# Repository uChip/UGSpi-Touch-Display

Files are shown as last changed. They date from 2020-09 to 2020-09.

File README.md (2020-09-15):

# UGSpi-Touch-Display
 A case for Rpi Display intended for DIY CNC router controller

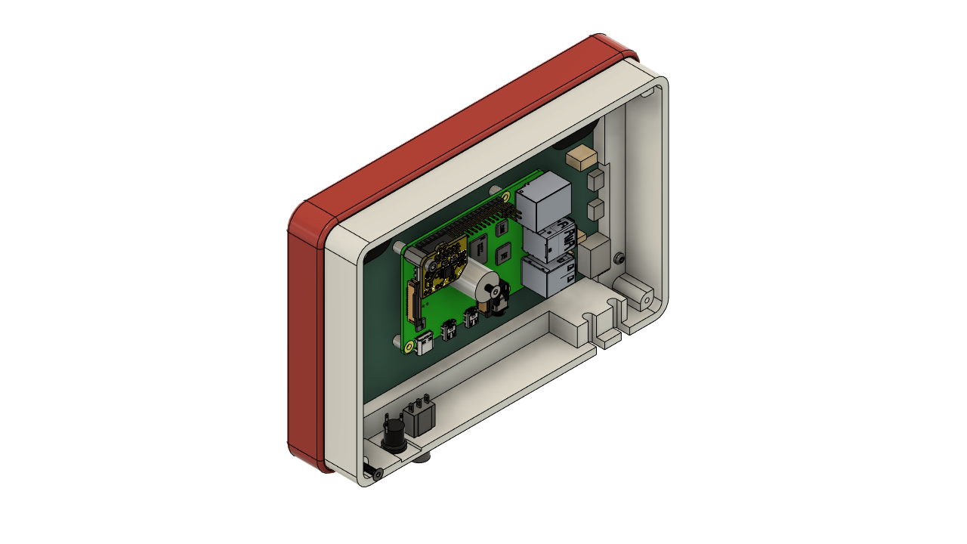
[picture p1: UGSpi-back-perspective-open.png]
UGSpi Case Rendering
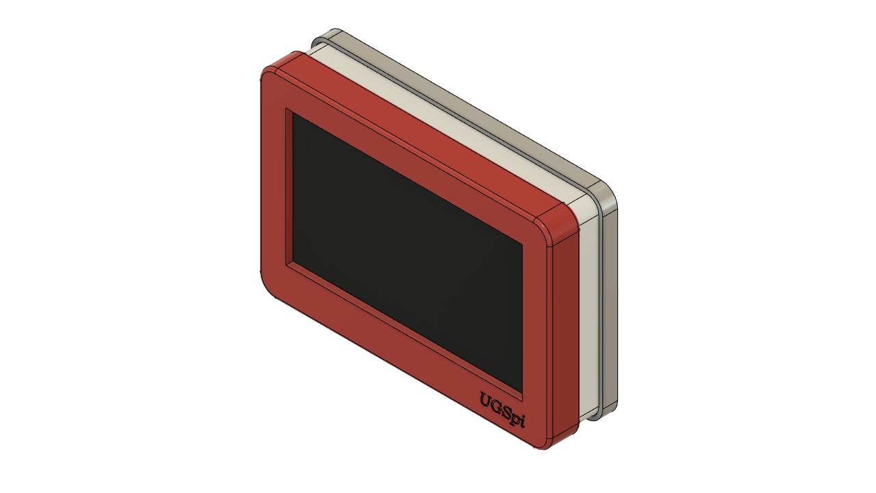
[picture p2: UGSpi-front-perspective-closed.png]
UGSpi Case Rendering
    
This repository gathers together various components to create a standalone computer to operate a DIY CNC router.  The computer is mostly off-the-shelf components but in a custom 3D-printed case and uses a small custom PCB to implement a soft-power switch to help with proper computer shutdown.  

The project includes:  
	- A sealed case with thermal management containing a Raspberry Pi and Display  
	- A ventilated case with a fan containing a Raspberry Pi and Display  
	- A step model for the given touch-display  
	- Instructions for loading and configuring UGS on Raspbian OS  
	- A custom PCB to implement a soft-power switch  
	- Code to implement the soft-power switch on an ATTiny85  
	
STL files also available at https://www.thingiverse.com/thing:4597083

This is a work in progress.  Use at your own risk.

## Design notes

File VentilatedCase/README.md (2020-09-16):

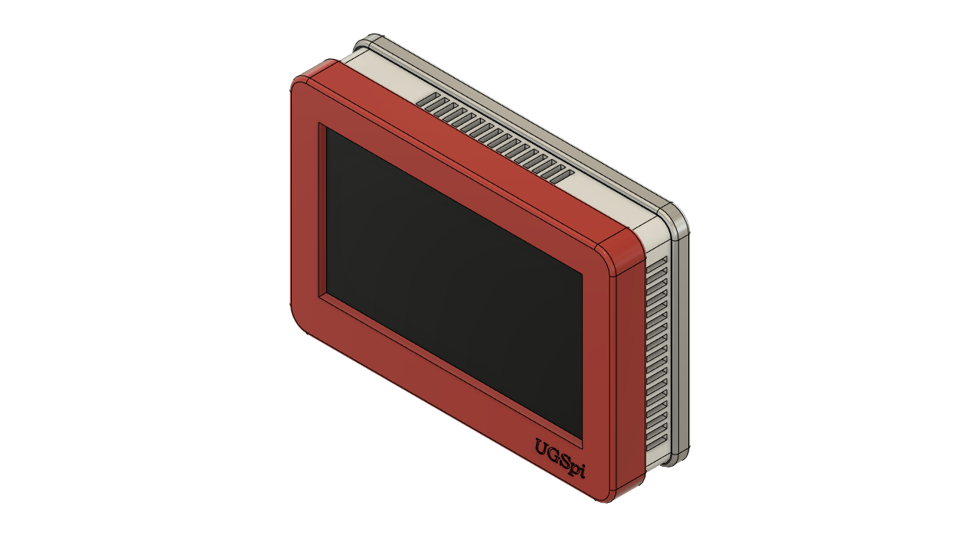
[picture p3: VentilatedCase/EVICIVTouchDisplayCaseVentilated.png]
UGSpi Ventilated Case Rendering
  
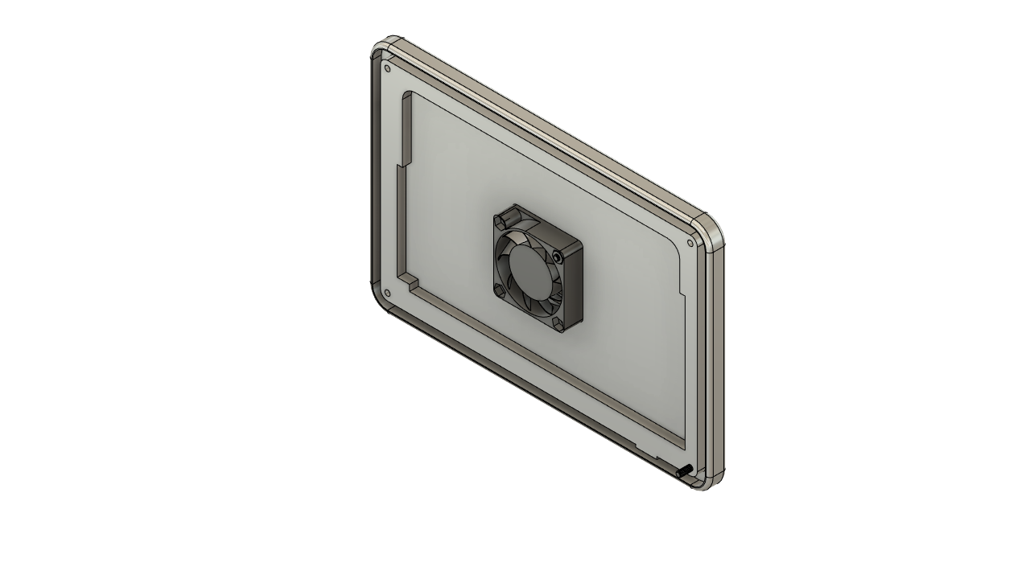
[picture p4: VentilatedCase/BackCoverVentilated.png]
UGSpi Case Rendering
  
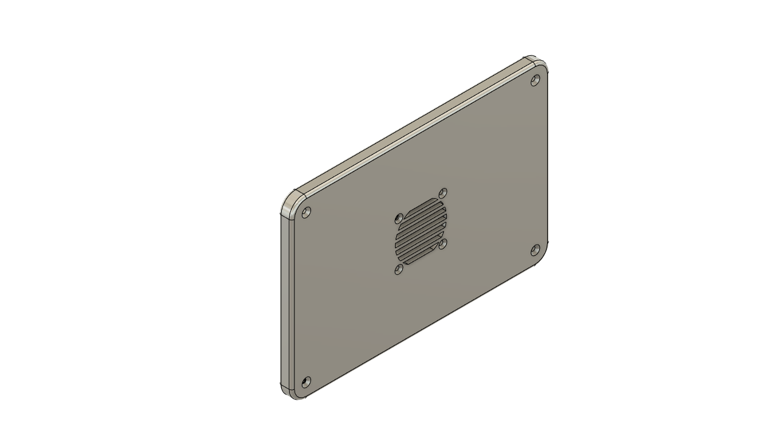
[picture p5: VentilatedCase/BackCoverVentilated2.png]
UGSpi Case Rendering


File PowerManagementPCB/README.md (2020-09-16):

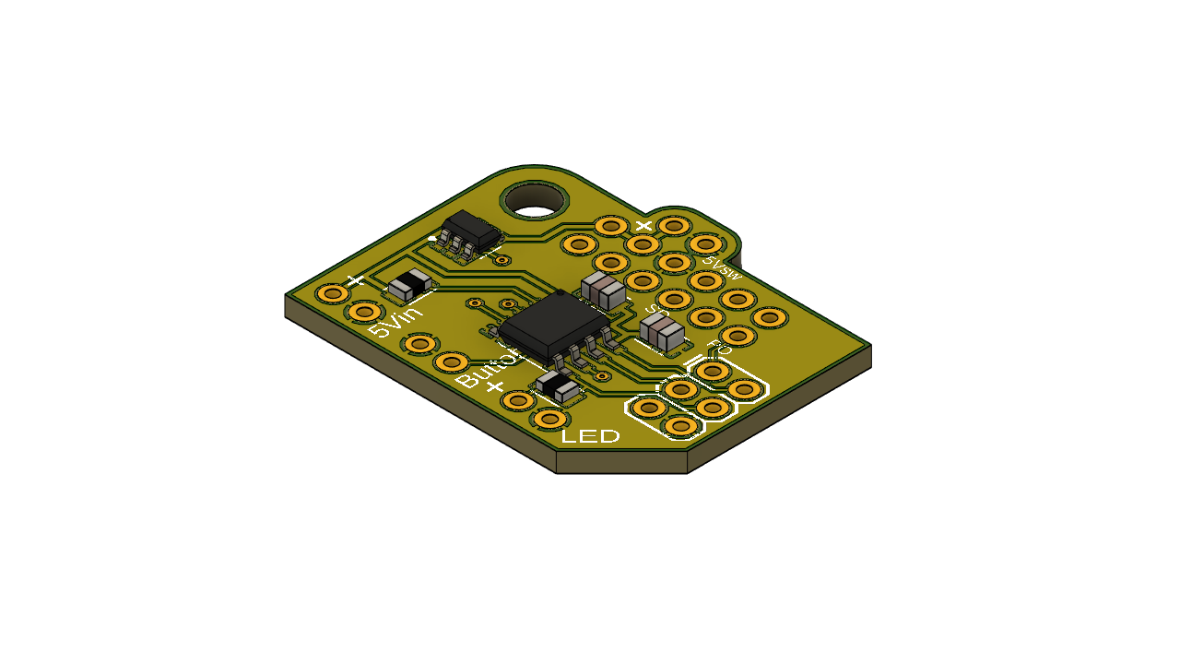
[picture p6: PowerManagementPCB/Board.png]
Power Management Board
  

Tapping power button when Raspberry Pi is OFF turns on 5V to Raspberry Pi & Display.  

Shutdown from Raspberry Pi menu signals board (when enabled) to turn off 5V to Raspberry Pi & Display.  

Tapping power button when Raspberry Pi is ON signals Raspberry Pi (when enabled) to shutdown.  

Holding down power button for 3 seconds turns off 5V to Raspberry Pi & Display.  

LED Indicator:  
Breathing - power to pi is off, ready to power on  
On - power to pi is on  
Flashing - Waiting for pi to signal ok to power off  
Off - power to pi is off or no power in

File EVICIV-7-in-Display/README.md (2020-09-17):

# Eviciv 7" Touch-Display  
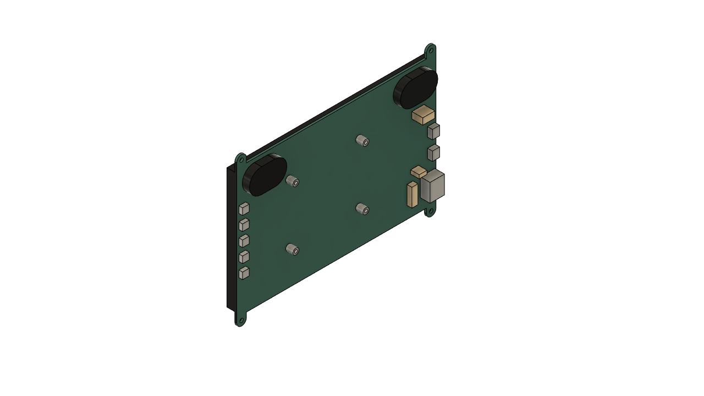
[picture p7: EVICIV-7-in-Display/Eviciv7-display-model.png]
Touch-Display Model
  

# Where to Buy

I bought mine from Amazon:
https://smile.amazon.com/Eviciv-Portable-Monitor-Display-1024X600/dp/B07L6WT77H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

Also found on:
https://www.aliexpress.com/item/33029514152.html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,searchweb201602_,searchweb201603_

NOTE: The internal cables are listed as "gifts" rather than as part of the product.  Since they are one of the major reasons for choosing this display, read the description carefully to see they are included before you buy.

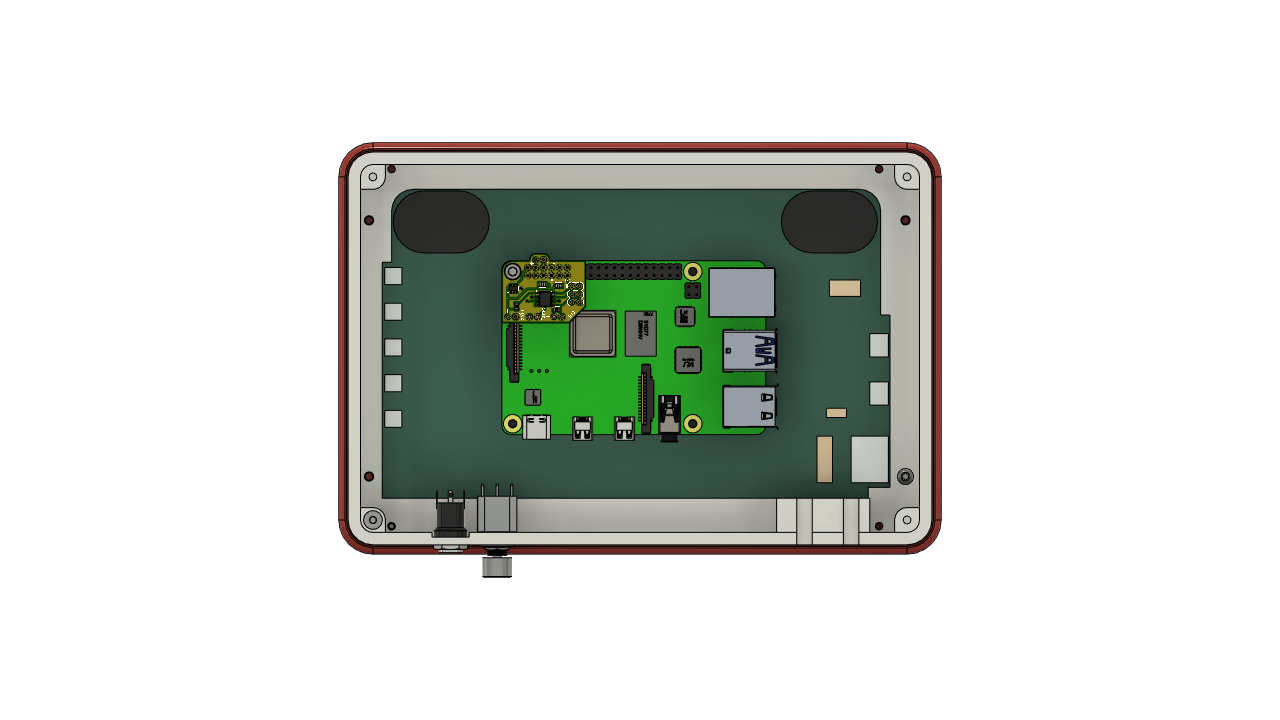
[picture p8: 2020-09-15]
UGSpi-back.png

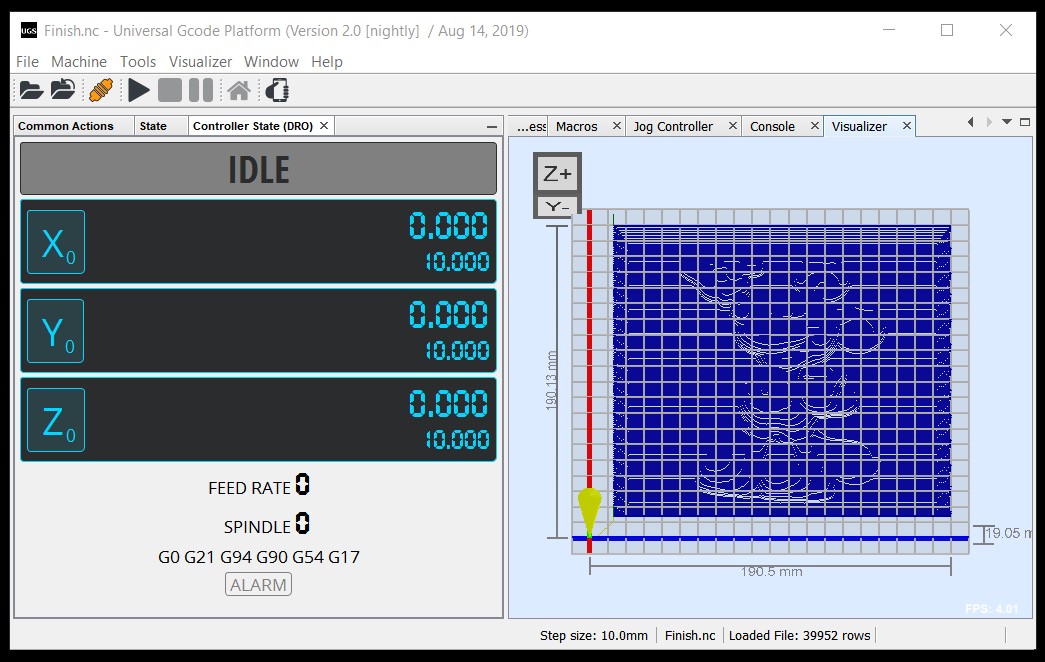
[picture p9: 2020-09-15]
UGSscreenshot.jpg

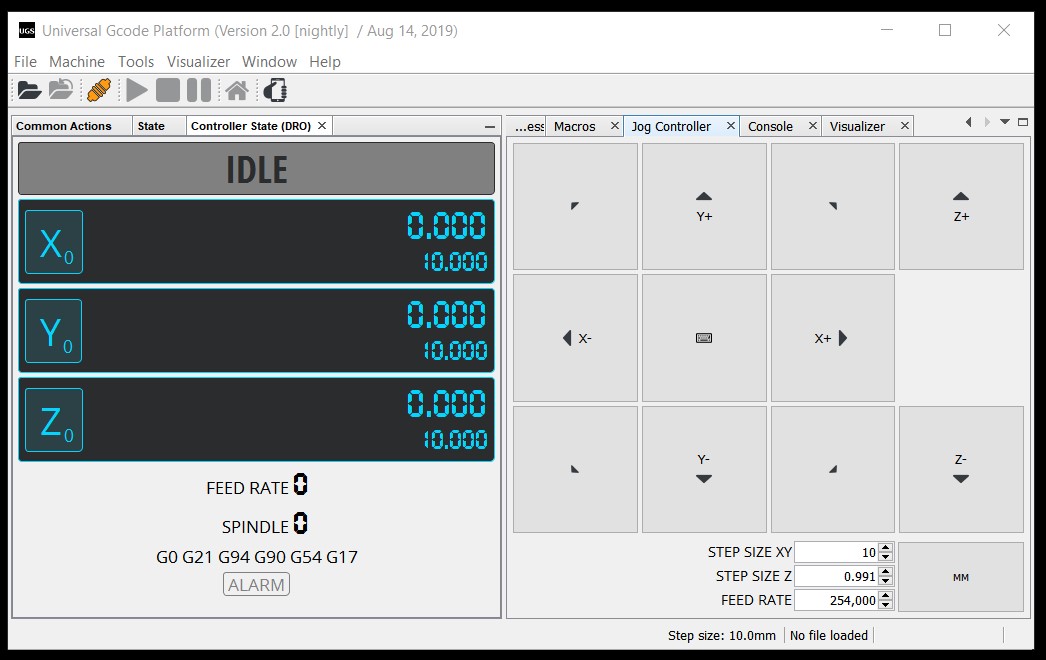
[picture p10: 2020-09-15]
UGSscreenshot2.jpg

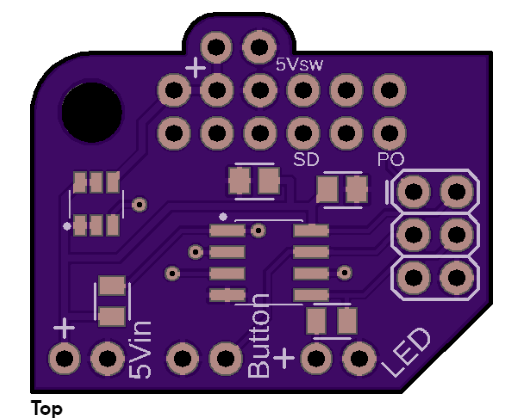
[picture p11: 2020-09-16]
PowerManagementPCB/OSHParkBoard.png

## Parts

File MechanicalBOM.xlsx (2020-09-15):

UGSpi Bill of Materials
Qty | Description | Reference
1 | Bezel | 3D Printed
1 | Frame | 3D Printed
1 | Back Cover | Milled Aluminum
1 | Display | Eviciv 7" touch-display https://smile.amazon.com/Eviciv-Portable-Monitor-Display-1024X600/dp/B07L6WT77H
1 | Computer | Raspberry Pi 4
1 | Power Manager | Custom PCB
1 | Power Jack | McMaster-Carr dc-jack-163-mj21-ex
1 | Soft-power Switch | 7400K41
4 | Display to Frame screw | McMaster-Carr 96817A908
4 | Frame to Bezel screw | McMaster-Carr 96817A912
1 | Standoff | McMaster-Carr 98952A019
4 | PCB to Standoff | McMaster-Carr 91292A110
4 | Back Cover to Frame | McMaster-Carr 92125A103
Vented version
1 | Back Cover-ventilated | 3D Printed
1 | Frame-ventilated | 3D Printed
1 | 40x40 fan | 40x40x10 e.g. https://smile.amazon.com/Noctua-Cooling-Blades-Bearing-NF-A4x10/dp/B009NQLT0M
4 | Back Cover to Fan | McMaster-Carr 92125A133
4 | Fan nut | McMaster-Carr 91828A211

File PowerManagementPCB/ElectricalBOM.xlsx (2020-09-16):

Power Management Board Bill of Materials
Qty | Description | Reference
1 | ‎FDC608PZ‎ ON Semiconductor MOSFET P-CH 20V 5.8A SSOT-6 | Digikey ‎FDC608PZCT-ND‎
1 | ‎ATTINY85-20SU‎ Microchip Technology IC MCU 8BIT 8KB FLASH 8SOIC | Digikey ‎ATTINY85-20SU-ND‎
1 | PPPC062LFBN-RC‎ Sullins Connector Solutions CONN HDR 12POS 0.1 GOLD PCB | Digikey ‎‎S7109-ND‎
1 | ‎ERJ-PB6D3300V‎ Panasonic Electronic Components RES SMD 330 OHM 0.5% 1/4W 0805 | Digikey ‎‎P20962CT-ND‎
1 | RNCF0805DTE10K0‎ Stackpole Electronics Inc RES 10K OHM 0.5% 1/8W 0805 | Digikey ‎RNCF0805DTE10K0CT-ND‎
1 | C0805C104Z5VACTU‎ KEMET CAP CER 0.1UF 50V Y5V 0805 | Digikey ‎399-1177-1-ND‎
1 | C0805C106Z8VACTU‎ KEMET CAP CER 10UF 10V Y5V 0805 | Digikey ‎‎399-8015-1-ND‎

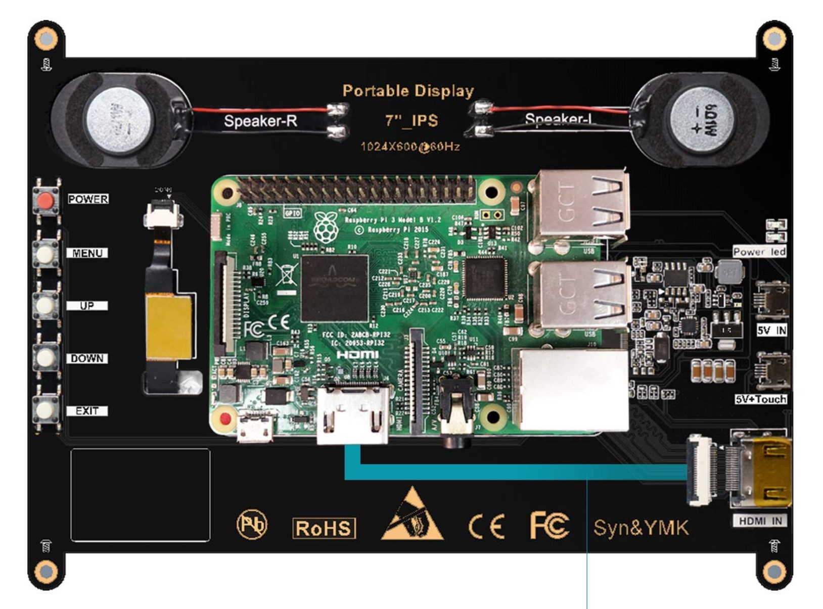
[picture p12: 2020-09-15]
EVICIV-7-in-Display/ComponentSide.jpg

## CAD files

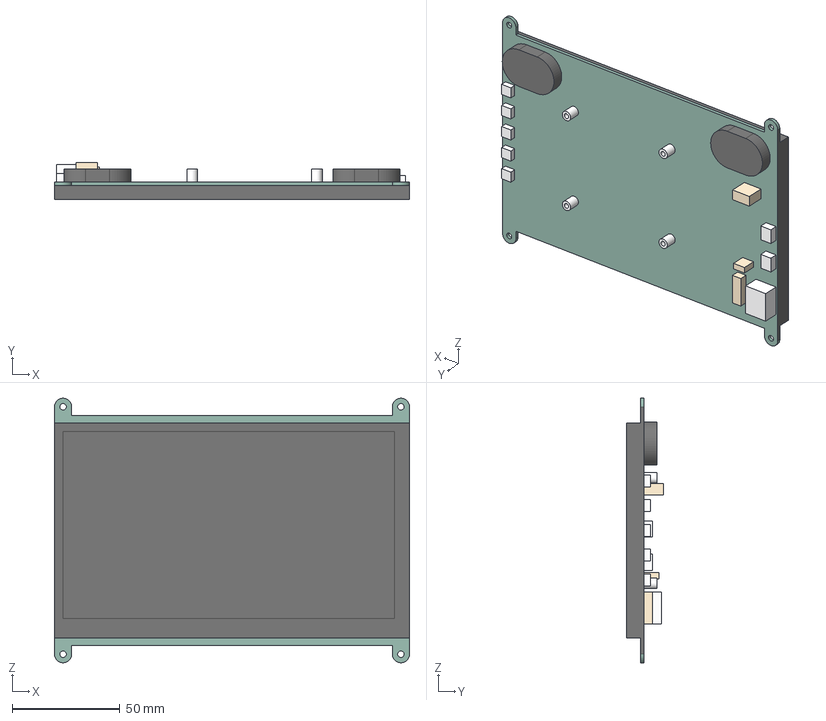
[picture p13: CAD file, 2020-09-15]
EVICIV-7-in-Display/EVICIV 7in Display.step
165.0 x 17.2 x 123.0 mm

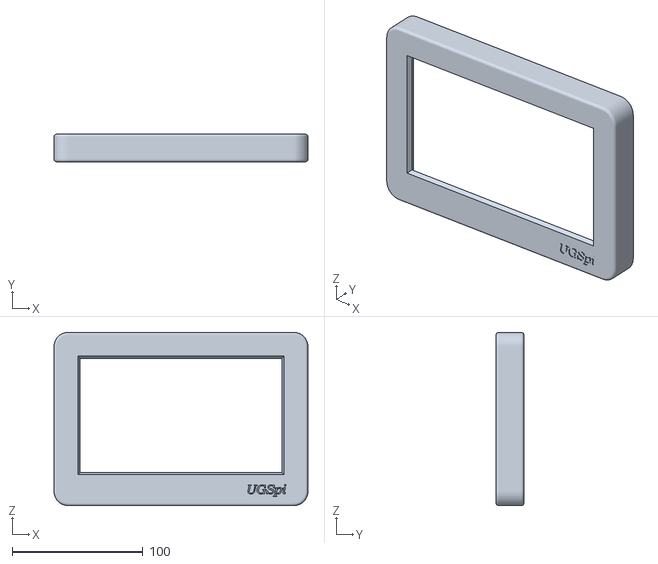
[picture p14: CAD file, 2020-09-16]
SealedCase/Bezel.stl
194.0 x 21.2 x 132.5

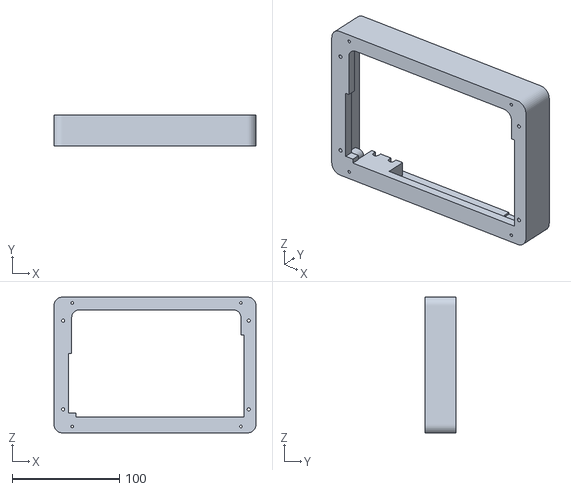
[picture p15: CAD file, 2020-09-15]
SealedCase/Frame.stl
188.0 x 29.0 x 126.5

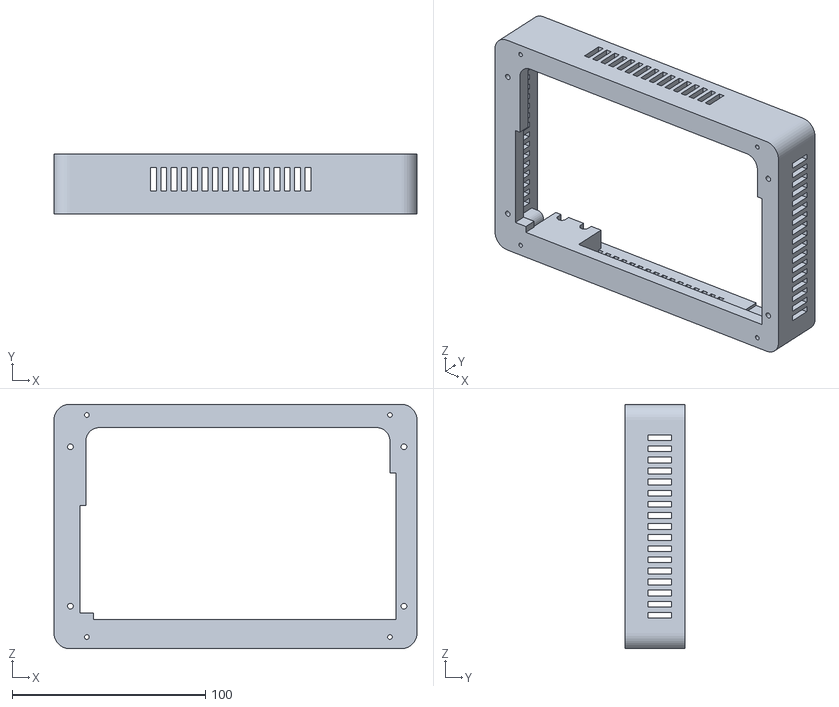
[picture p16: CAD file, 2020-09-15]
VentilatedCase/Frame-ventilated.stl
188.0 x 31.0 x 126.5

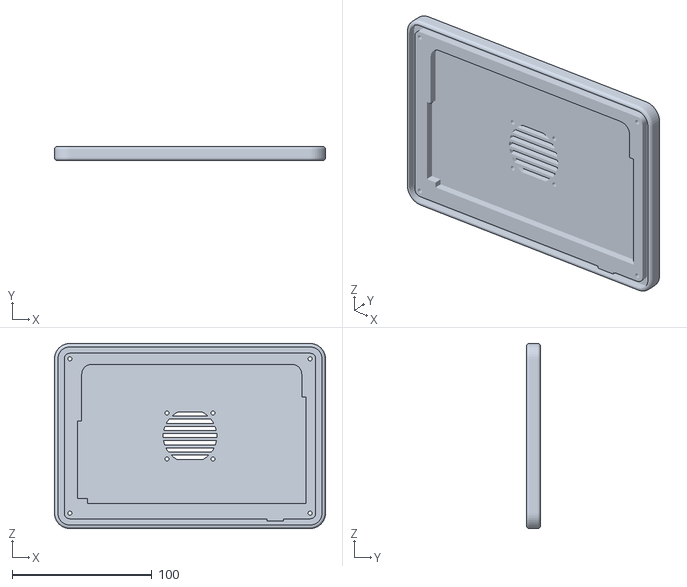
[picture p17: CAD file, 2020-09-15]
VentilatedCase/BackCover-40x40-fan.stl
194.0 x 10.0 x 132.5

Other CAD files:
VentilatedCase/Bezel-no-logo.stl
SealedCase/Bezel-no-logo.stl
EVICIV-7-in-Display/EVICIV 7in Display.stl

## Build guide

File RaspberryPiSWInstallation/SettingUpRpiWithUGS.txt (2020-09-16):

This mostly works, but seems a little unstable.  Everything is fine up to Autostarting the UGS application.

Load Raspian image to SD card
Boot Raspbian
Update image
Use raspi-config to change the following
  Set wait for network
  Activate OpenGL driver: choose Advanced Options >> GL  Driver >> GL (Fake KMS).
  Expand the file system: Advanced Options >> Expand the file system.

Install Java
  sudo apt install openjdk-8-jdk

Load UGSplatform
  download zip
  unpack
  Fix a problem showing simulation 
    sudo mv /opt/vc /opt/vc.old

Mount the drop folder shared from Windows
  sudo nano /etc/fstab
  append
  //192.168.1.11/DropFolder /home/pi/Desktop/DropFolder cifs username=<username>,password=<password> 0 0

Pull down (open collector) on GPIO4 to initiate shutdown (pin7)
Shutdown in progress will raise GPIO17 (pin11)
  sudo nano /boot/config.txt
  append
    dtoverlay=gpio-poweroff,gpiopin=17,active_low=0
Pin 11 will go high when Rpi is ready to have power removed
    dtoverlay=gpio-shutdown,gpiopin=4,active_low=1,gpio_pull=up
Pulling pin 4 low will cause the Rpi to initiate shutdown

NOTE: power must be removed within 3 seconds of gpio-poweroff or kernel panic will occur

Autostart UGS:

sudo nano /lib/systemd/system/startUGS.service
[Unit]
Description=Start UGS application

[Service]
Environment=DISPLAY=:0
Environment=XAUTHORITY=/home/pi/.Xauthority
ExecStart=/home/pi/ugsplatform/bin/ugsplatform
Restart=always
RestartSec=10s
KillMode=process
TimeoutSec=infinity

[Install]
WantedBy=graphical.target

Then to activate the change:
  sudo systemctl daemon-reload
  sudo systemctl enable startUGS.service
To stop the autostart when running:
  sudo systemctl stop startUGS.service
To disable the autostart:
  sudo systemctl disable startUGS.service
To remove the autostart from the table:
  sudo rm /lib/systemd/system/startUGS.service
  sudo systemctl daemon-reload

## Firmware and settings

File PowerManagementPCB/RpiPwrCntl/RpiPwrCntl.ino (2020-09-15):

// Define hardware connections
//   Arduino definition of a ATtiny85
//     p1 - Reset (active low) <-- pulled high
//     p2 - A3 or 3          <-- Rpi signals shutdown in progress active high
//     p3 - A2 or 4          <-- Power control pin active low
//     p4 - GND
//     p5 - 0 (pwm capable)  <-- LED output
//     p6 - 1 (pwm capable)  <-- Request Rpi to shutdown active low
//     p7 - A1 or 2          <-- Button input (closure to ground)
//     p8 - Vcc

// This hardware is wired as follows
#define BUTTONpin 2
#define SD_ACKpin 3
#define SD_REQpin 1
#define LEDpin 0
#define POWERpin 4

//Button Events
#define NOEVENT 0
#define SHORTPRESS 1
#define LONGPRESS 2

//Button state
#define UP true
#define DOWN false

//LED modes
#define LED_ON 1
#define LED_OFF 2
#define LED_BLINK 3
#define LED_BREATH 4
#define FULLON 255
#define FULLOFF 0

//Controller State
#define SLEEP 1
#define PWRON 2
#define REQSHUTDOWN 3
#define PWROFF 4

//Long press timer
#define BTIMEOUT 60


int LEDMode;
int State;
int ButtonEvent;
int lastButton;
int thisButton;

long ButtonTimer;
long LEDTimer;
int LEDval;

int breatharray[16] = {
  0,
  36,
  73,
  109,
  
  145,
  181,
  227,
  255,
  
  255,
  227,
  181,
  145,
  
  109,
  73,
  36,
  0,
};
int breathcount;

int myCheckButton() {
  lastButton = thisButton;
  thisButton = digitalRead(BUTTONpin);

  //Falling Edge
  if (lastButton == UP && thisButton == DOWN) {
    ButtonTimer = 0;
    return NOEVENT;
  }

  //Rising Edge
  if (lastButton == DOWN && thisButton == UP) {
    if (ButtonTimer < BTIMEOUT) return SHORTPRESS;
    else return LONGPRESS;
  }

  //Still Down
  if (lastButton == DOWN && thisButton == DOWN) {
    ButtonTimer++;
    if (ButtonTimer >= BTIMEOUT) return (LONGPRESS);
    else return NOEVENT;
  }

  return NOEVENT;
}


void UpdateLED() {
  LEDTimer++;
  if (LEDTimer > 4) {
    LEDTimer = 0;
    switch (LEDMode) {
      case LED_BLINK:
        if (LEDval > FULLOFF) LEDval = FULLOFF;
        else LEDval = FULLON;
        break;
      case LED_OFF:
        LEDval = FULLOFF;
        break;
      case LED_ON:
        LEDval = FULLON;
        break;
      case LED_BREATH:
        breathcount++;
        if (breathcount > 15) breathcount = 0;
        LEDval = breatharray[breathcount];
        break;
      default: break;
    }
    analogWrite(LEDpin, LEDval);
  }
}


void setup() {
  pinMode(BUTTONpin, INPUT_PULLUP);
  pinMode(SD_ACKpin, INPUT);
  pinMode(SD_REQpin, INPUT);
  pinMode(LEDpin, OUTPUT);
  pinMode(POWERpin, OUTPUT);

  digitalWrite(SD_REQpin, LOW);
  analogWrite(LEDpin, FULLOFF);
  digitalWrite(POWERpin, false);

  LEDMode = LED_OFF;
  State = SLEEP;

}

void loop() {
  ButtonEvent = myCheckButton();  // Returns NOEVENT, SHORTPRESS, or LONGPRESS
  UpdateLED();

  switch (State) {
    case SLEEP: {
        digitalWrite(POWERpin, false); //turn power OFF
        LEDMode = LED_BREATH;
        // digitalWrite(SD_REQpin, false); // no shutdown req
        pinMode(SD_REQpin, INPUT);  //turn off shutdown req, go from output LOW to hiZ
        if (ButtonEvent == SHORTPRESS) State = PWRON;
        if (ButtonEvent == LONGPRESS) State = PWROFF;
        break;
      }
    case PWRON: {
        digitalWrite(POWERpin, true); //turn power ON
        LEDMode = LED_ON;
        // digitalWrite(SD_REQpin, false); // no shutdown req
        pinMode(SD_REQpin, INPUT);  //turn off shutdown req, go from output LOW to hiZ
        if (ButtonEvent == SHORTPRESS) State = REQSHUTDOWN;
        if (ButtonEvent == LONGPRESS) State = PWROFF;
        if (digitalRead(SD_ACKpin) == true) {
          delay(100);
          State = PWROFF;
        }
        break;
      }
    case REQSHUTDOWN: {
        digitalWrite(POWERpin, true); //turn power ON
        LEDMode = LED_BLINK;
        // digitalWrite(SD_REQpin, LOW); //Request Shutdown
        pinMode(SD_REQpin, OUTPUT);  //Request Shutdown, go from hiZ to output LOW
        //if(ButtonEvent == SHORTPRESS) State = REQSHUTDOWN;
        if (ButtonEvent == LONGPRESS) State = PWROFF;
        if (digitalRead(SD_ACKpin) == true) {
          delay(100);
          State = PWROFF;
        }
        break;
      }
    case PWROFF: {
        digitalWrite(POWERpin, false); //turn power OFF
        LEDMode = LED_OFF;
        //digitalWrite(SD_REQpin, false); // no shutdown req
        pinMode(SD_REQpin, INPUT);  //turn off shutdown req, go from output LOW to hiZ
        if (ButtonEvent == LONGPRESS) {
          State = PWROFF;
        }
        else State = SLEEP;
        break;
      }
    default: State = SLEEP;
  }

  delay(50);
}

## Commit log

2020-09-15 Initial organization & seeding
    [BackCover-40x40-fan.stl, BackCover.stl, Bezel-no-logo.stl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]
2020-09-16 Updated board defn
2020-09-16 Fixed Bexel clearance & added renderings of ventilated case
    [Bezel-no-logo.stl, Bezel.stl]
